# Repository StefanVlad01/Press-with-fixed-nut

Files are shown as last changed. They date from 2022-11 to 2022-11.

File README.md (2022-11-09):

# Press-with-fixed-nut
Manually operated screw presses are used in machine building, in machine shops, for bending and embossing relatively small 
parts.
They are also used to make tight assemblies and the technological molding operation.
This is the first serious project I worked on and it made me realize that I have a passion for design and 3D modeling.

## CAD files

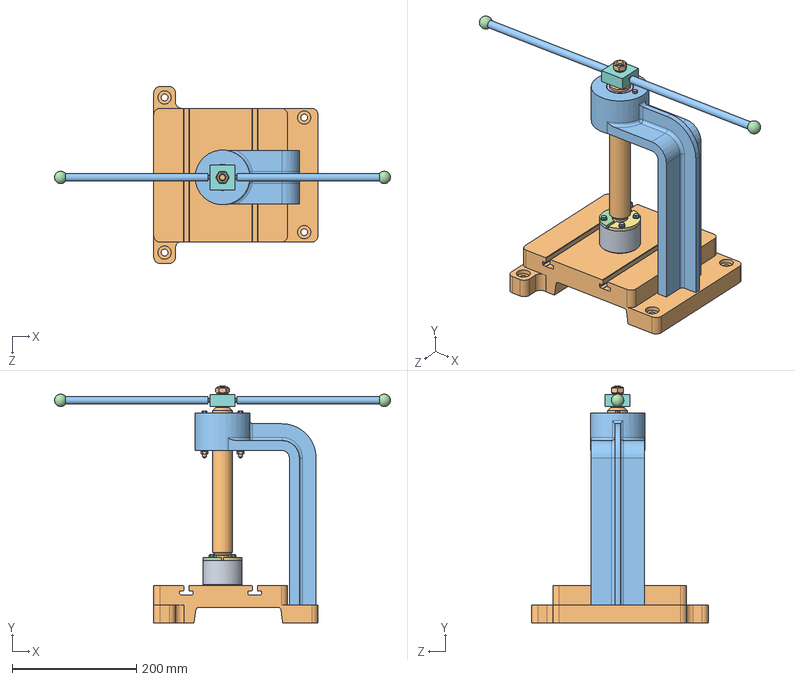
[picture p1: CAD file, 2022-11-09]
Press with fixed nut.SLDASM
540.0 x 380.2 x 284.3 mm
Berbec
Surub
SKF_51204_3 x 12
SKF_51204_16
SKF_51204_18
Piulita
Inel1
Surub berbec x 4
Saiba x 4
Masa-Corp
Brat
Inel2
Surub brat x 2
Saiba brat x 2
Piulita brat x 2
Butuc
Saiba cap
Piulita cap
Maner x 2
Sfera x 2

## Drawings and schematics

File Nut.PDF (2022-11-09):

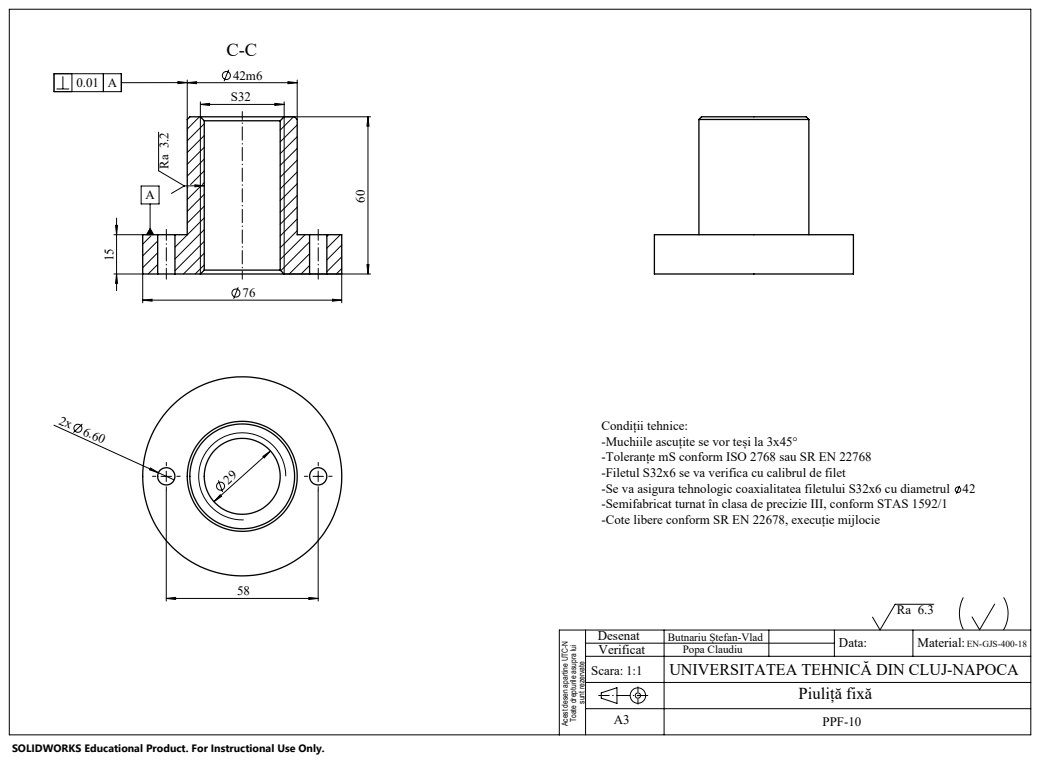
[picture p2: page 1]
sunt rezervate; Popa Claudiu; EN-GJS-400-18; Piuliță fixă

Condiții tehnice:
-Muchiile ascuțite se vor teși la 3x45°
-Toleranțe mS conform ISO 2768 sau SR EN 22768
-Filetul S32x6 se va verifica cu calibrul de filet
-Se va asigura tehnologic coaxialitatea filetului S32x6 cu diametrul 42
-Semifabricat turnat în clasa de precizie III, conform STAS 1592/1
-Cote libere conform SR EN 22678, execuție mijlocie

Butnariu Ștefan-Vlad
UNIVERSITATEA TEHNICĂ DIN CLUJ-NAPOCA

Acest desen apartine UTC-N

Toate drepturile asupra lui

SOLIDWORKS Educational Product. For Instructional Use Only.

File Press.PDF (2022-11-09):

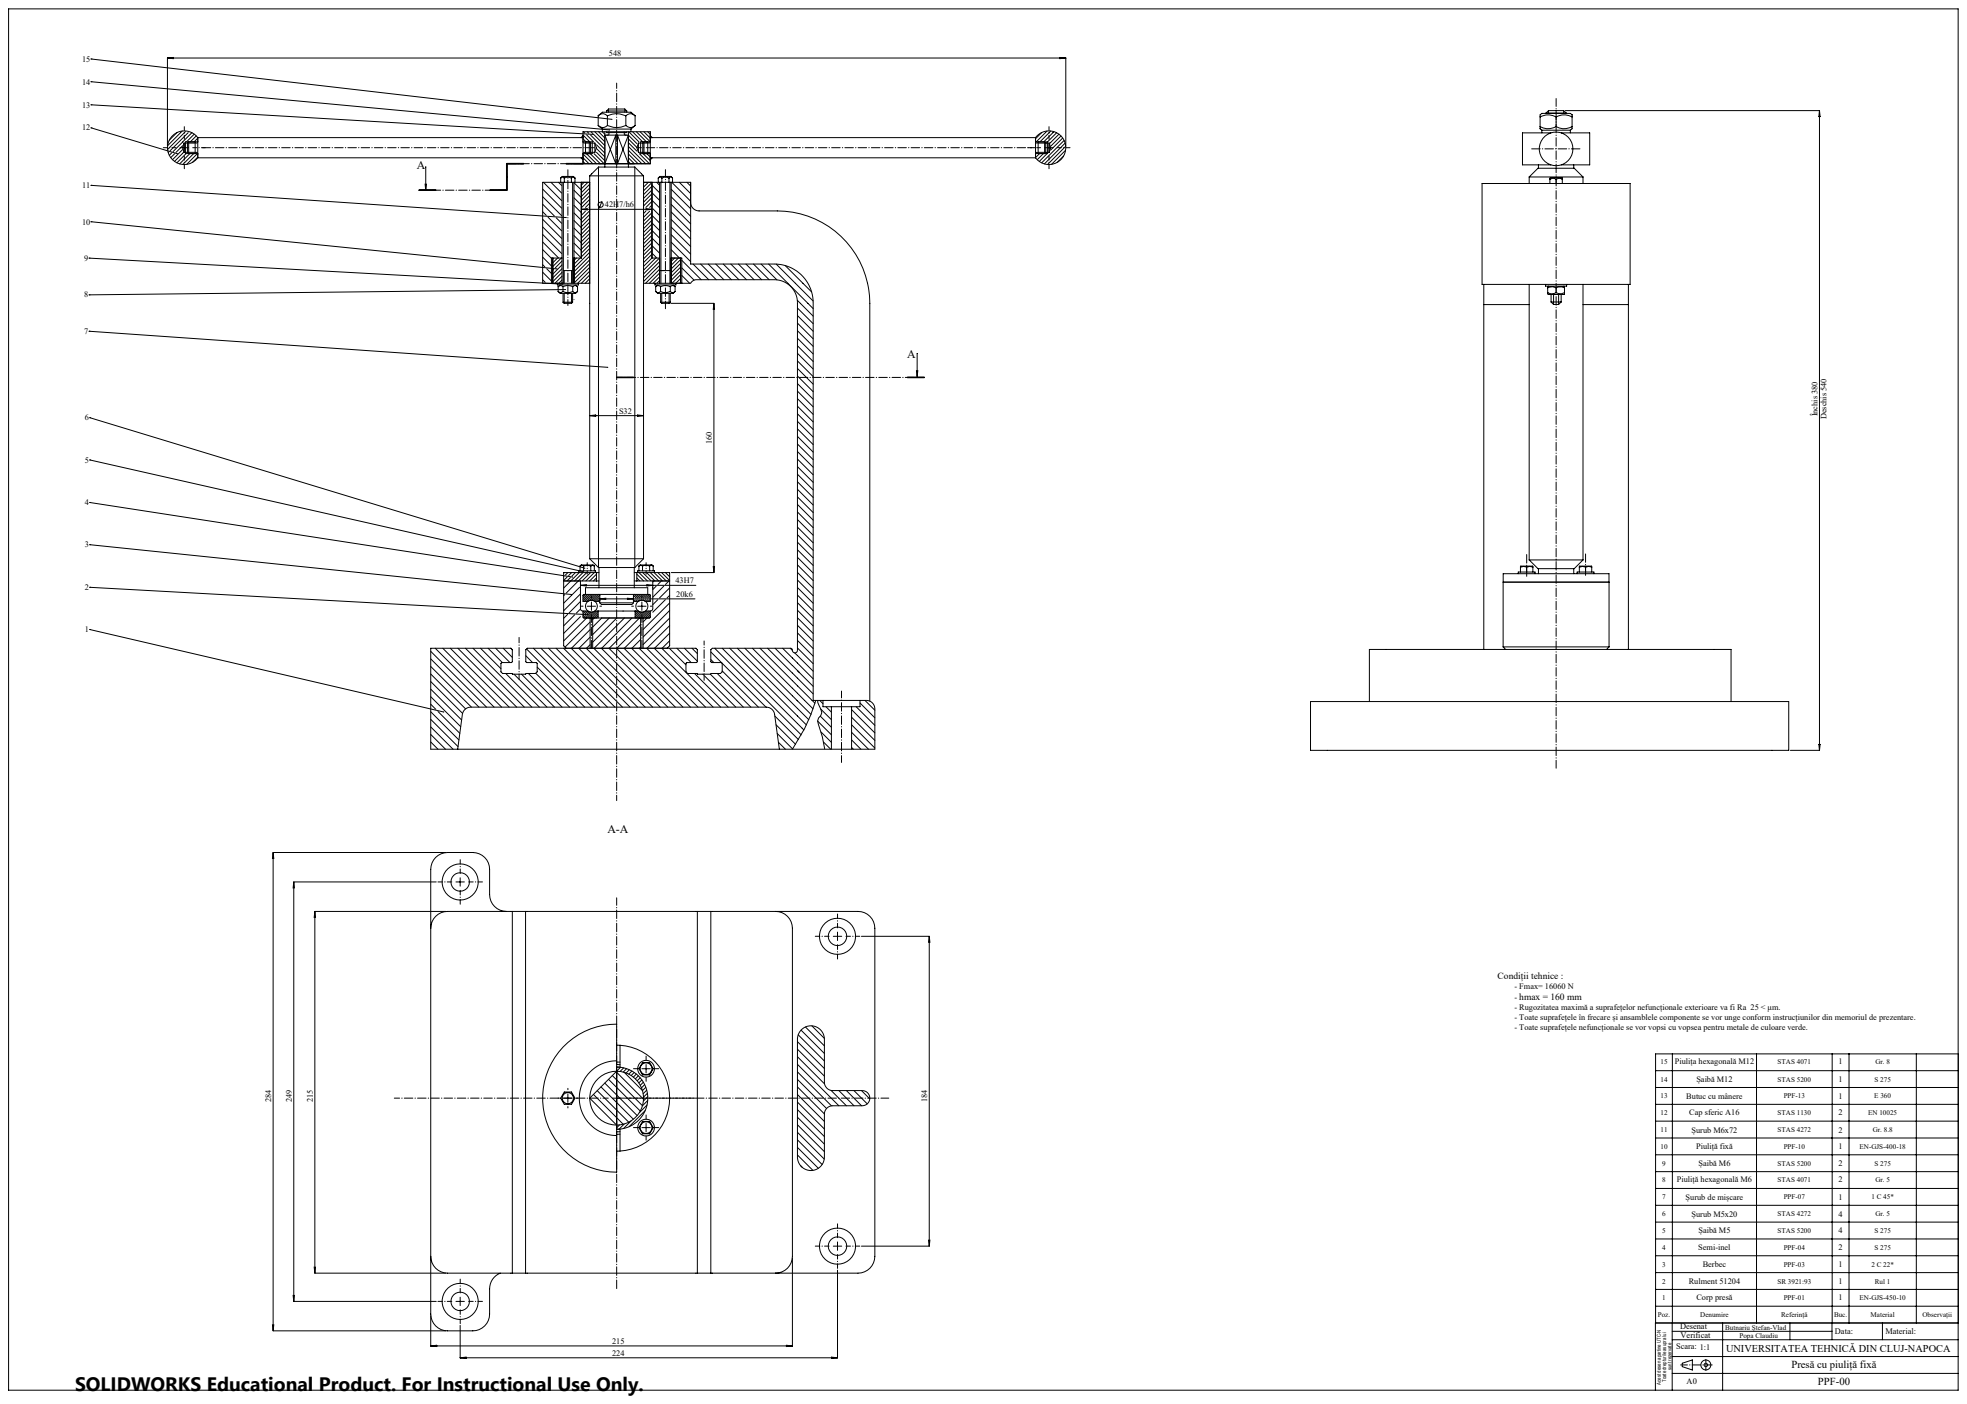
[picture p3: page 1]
sunt rezervate; Închis 380; Deschis 540

Condiții tehnice :
- Fmax= 16060 N
- hmax = 160 mm
- Rugozitatea maximă a suprafețelor nefuncționale exterioare va fi Ra 25 < μm.
- Toate suprafețele în frecare și ansamblele componente se vor unge conform instrucțiunilor din memoriul de prezentare.
- Toate suprafețele nefuncționale se vor vopsi cu vopsea pentru metale de culoare verde.

15 | Piulița hexagonală M12 | STAS 4071 | 1 | Gr. 8
14 | Șaibă M12 | STAS 5200 | 1 | S 275
13 | Butuc cu mânere | PPF-13 | 1 | E 360
12 | Cap sferic A16 | STAS 1130 | 2 | EN 10025
11 | Șurub M6x72 | STAS 4272 | 2 | Gr. 8.8
10 | Piuliță fixă | PPF-10 | 1 | EN-GJS-400-18
9 | Șaibă M6 | STAS 5200 | 2 | S 275
8 | Piuliță hexagonală M6 | STAS 4071 | 2 | Gr. 5
7 | Șurub de mișcare | PPF-07 | 1 | 1 C 45*
6 | Șurub M5x20 | STAS 4272 | 4 | Gr. 5
5 | Șaibă M5 | STAS 5200 | 4 | S 275
4 | Semi-inel | PPF-04 | 2 | S 275
3 | Berbec | PPF-03 | 1 | 2 C 22*
2 | Rulment 51204 | SR 3921:93 | 1 | Rul 1
1 | Corp presă | PPF-01 | 1 | EN-GJS-450-10

Poz. | Denumire | Referință | Buc. | Material | Observații

Butnariu Ștefan-Vlad
Popa Claudiu
UNIVERSITATEA TEHNICĂ DIN CLUJ-NAPOCA

Acest desen apartine UTC-N

Toate drepturile asupra lui

Presă cu piuliță fixă
PPF-00

SOLIDWORKS Educational Product. For Instructional Use Only.

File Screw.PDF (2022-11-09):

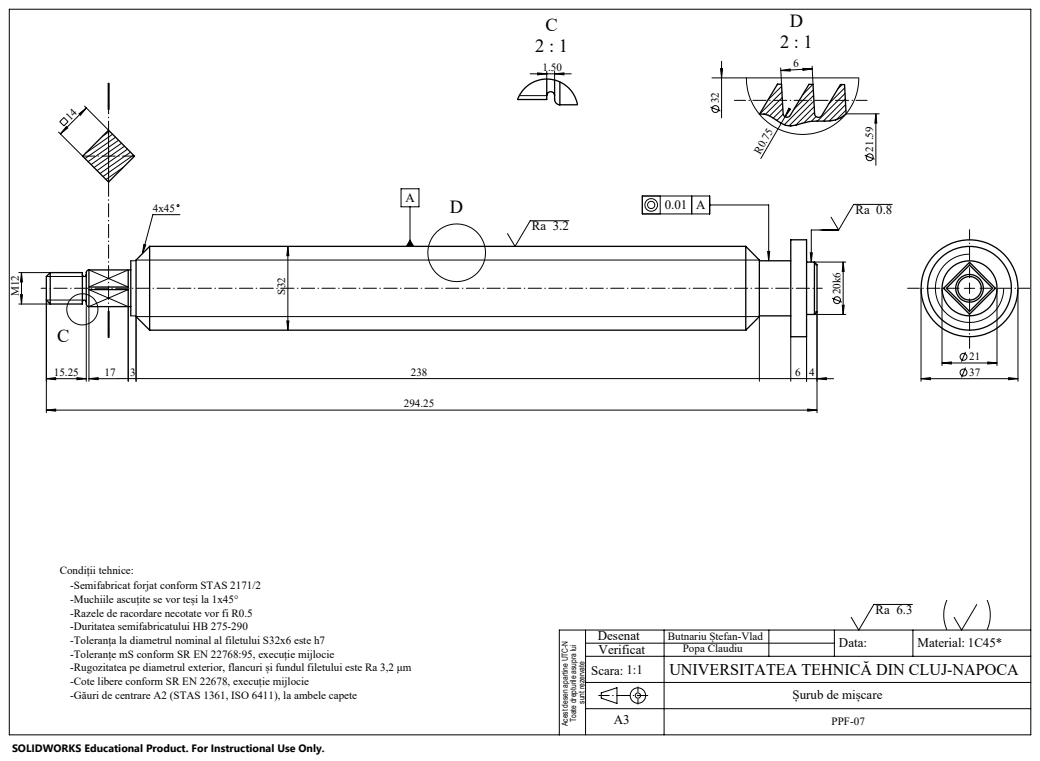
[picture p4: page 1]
sunt rezervate; Popa Claudiu

Condiții tehnice:
-Semifabricat forjat conform STAS 2171/2
-Muchiile ascuțite se vor teși la 1x45°
-Razele de racordare necotate vor fi R0.5
-Duritatea semifabricatului HB 275-290
-Toleranța la diametrul nominal al filetului S32x6 este h7
-Toleranțe mS conform SR EN 22768:95, execuție mijlocie
-Rugozitatea pe diametrul exterior, flancuri și fundul filetului este Ra 3,2 μm
-Cote libere conform SR EN 22678, execuție mijlocie
-Găuri de centrare A2 (STAS 1361, ISO 6411), la ambele capete

Butnariu Ștefan-Vlad
UNIVERSITATEA TEHNICĂ DIN CLUJ-NAPOCA

Acest desen apartine UTC-N

Toate drepturile asupra lui

Șurub de mișcare

SOLIDWORKS Educational Product. For Instructional Use Only.
